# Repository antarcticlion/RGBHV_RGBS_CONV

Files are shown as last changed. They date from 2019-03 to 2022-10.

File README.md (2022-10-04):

# RGB MULTI CONV

Display/Monitor video signal converter PCB for Japanese Retro PC (RGBHV &lt;--> RGBS ./ etc. )

##概要

主に日本製のレトロPCのRGB信号を、コネクタ変換・信号変換・分岐を行うボードです。
Rev1.5でサブボードをスタックして扱うコネクタを増やせるようにしています。
プロジェクトにはKiCad PCB 5.0用のプロジェクトファイルとガーバーが含まれます。

##外観
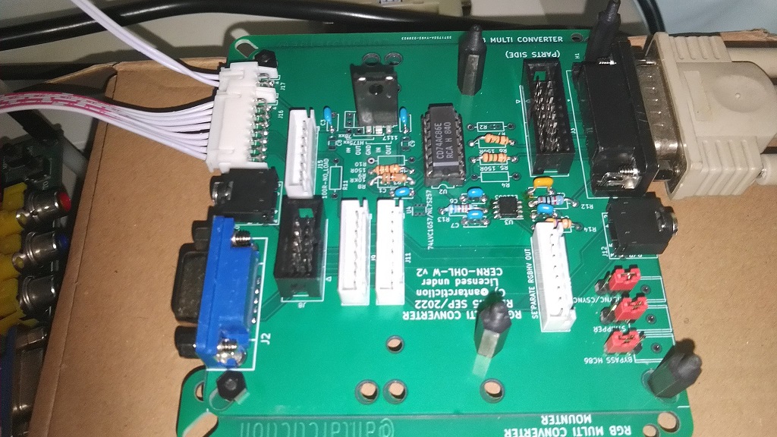
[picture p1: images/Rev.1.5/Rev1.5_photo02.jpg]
Rev15 converter pcb_photo 1
  
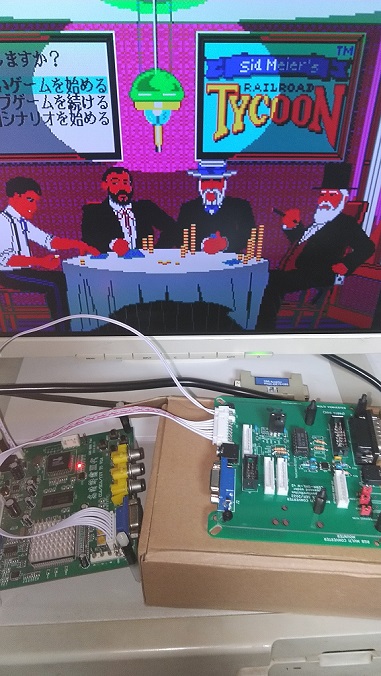
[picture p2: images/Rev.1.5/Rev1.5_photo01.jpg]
Rev15 converter pcb_photo 1
  

## 動作確認済機種
### Video signal src.
- IBM-PC compatible (VGA)  
- PC-8801mk2 (Digital RGB 8p)  
- PC-8801mk2MR/FH (Digital RGB 8p/Analog RGB DA15)  
- PC-9801DA/U2 (Analog RGB DA15)  
- PC-9801VX41 (Digital RGB 8p/Analog RGB DA15)  
- X1 Turbo model40 (Digital RGB 8p)  
- X1 Turbo model30 (Digital RGB 6p)  
- MZ-700 (Digital RGB 8p)  
- FM-7 (Digital RGB 8p)  
- FM-new7 (Digital RGB 8p)  
- BASIC Master Level 3 (Digital RGB 8p)  
- Arcade-Game PCBs (クイズココロジー2／上海2／子育てクイズ マイエンジェル）(信号分岐、コネクタ変換)
- 上記の他、PC8001シリーズ(Digital RGB)で動作報告をいただいております。ありがとうございます。
### Video signal dst.
- GBS-8200/GBS-8220/HD9800V/HD-VC9900(RGBS)
- Some VGA monitors (DE15/VGA)

***
[概要](https://github.com/antarcticlion/RGBHV_RGBS_CONV/wiki)  
[作り方](https://github.com/antarcticlion/RGBHV_RGBS_CONV/wiki/How-to-make)  
[デザインと説明](https://github.com/antarcticlion/RGBHV_RGBS_CONV/wiki/Design)  
[その他](https://github.com/antarcticlion/RGBHV_RGBS_CONV/wiki/Miscellaneous)  
[リリースノート](https://github.com/antarcticlion/RGBHV_RGBS_CONV/wiki/Release-note)  

***
最新版 Rev1.5A
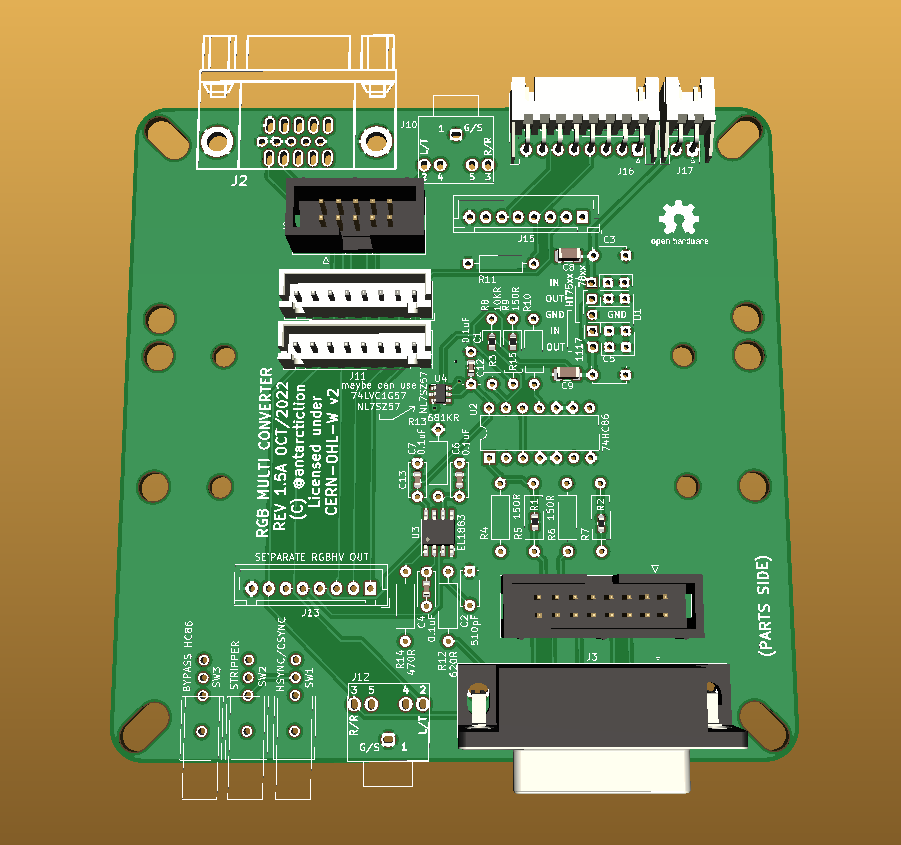
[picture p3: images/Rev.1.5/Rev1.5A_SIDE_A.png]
Rev15A converter pcb_art 1
  
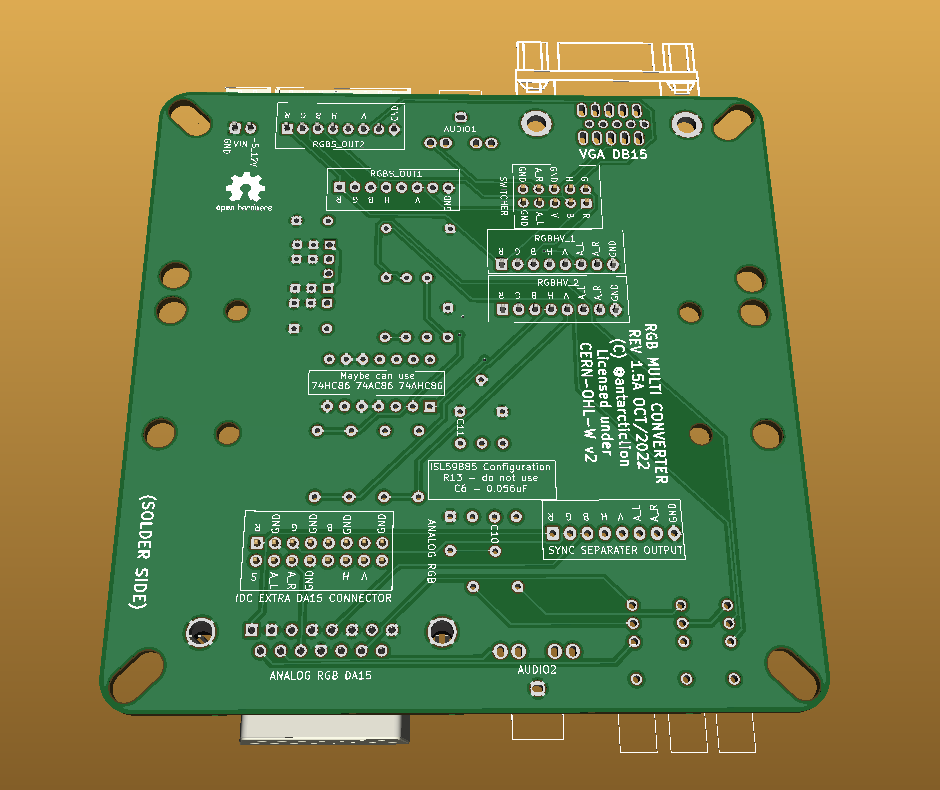
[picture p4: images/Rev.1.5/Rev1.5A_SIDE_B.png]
Rev15A converter pcb_art 2
  

***
# Lastest Gerber

### 1.5A  
https://github.com/antarcticlion/RGBHV_RGBS_CONV/blob/master/RGBHV_RGBS_CONV_15A.zip メインボード
https://github.com/antarcticlion/RGBHV_RGBS_CONV/blob/master/RGBHV_RGBS_CONV_EXTRA1_15.zip　デジタルRGBサブボード
https://github.com/antarcticlion/RGBHV_RGBS_CONV/blob/master/RGBHV_RGBS_CONV_stack_15.zip　GBSスタック用サブボード

## Arcive

### 1.0D  
https://github.com/antarcticlion/RGBHV_RGBS_CONV/blob/master/RGBHV_RGBS_CONV_10D.zip

***
# Changes Log  
| Revision | Date | Description |
|:---|:---|:---|
|1.5A release |2022/10/03 | スイッチのスルーホールサイズを変更 |
|1.5 release candidate |2022/09/23 | DE15/DA15を残し他のコネクタは小基板化、EL1883用パターンを追加、各種切り替えスイッチを付ける |
||2022/09/23 | 最新のガーバーファイルを残して古いものは削除 |
|1.0D release |2021/07/29 | DIN8コネクタのフットプリントが裏表逆になっていたのをFIX |
|1.0C release |2021/07/09 | RGBSへの音声パターンカット、レギュレータの足配置バリエーションの追加 |
|1.0B release |2021/05/11 | 3.3Vレギュレータによる電源安定化、3.3V駆動の5VトレラントCMOSロジックでGBS出力の無調整化(SN74AHC86N推奨) |
|0.5B release |2020/06/10 | RGBS出力に多回転VRを追加し、出力レベルを下げられるコネクタを用意。(GBS8200/8220のCSYNC信号不安定対策) |
|0.5A release |2019/08/28 | あまり使わないコネクタと、動悸分離回路を削除、RGBHV DA15のエッジ端コネクタを追加 |
|0.4A release candidate |2019/03/04 | コネクタ位置調整、DCジャック追加 |
|0.4 |2019/03/04 | first release. (experimental) |
|0.1～0.3 | N/A | private |

***
# ライセンス

2022/06/04 
Rev1.0D以降のライセンスを CERN Open Hardware Licence Version 2 - Weakly Reciprocal に変更します。
以前のバージョンのアーカイブは近日消します。

https://spdx.org/licenses/CERN-OHL-W-2.0.html
PDF https://github.com/antarcticlion/RGBHV_RGBS_CONV/blob/master/cern_ohl_w_v2.pdf
HOWTO https://github.com/antarcticlion/RGBHV_RGBS_CONV/blob/master/cern_ohl_w_v2_howto.pdf

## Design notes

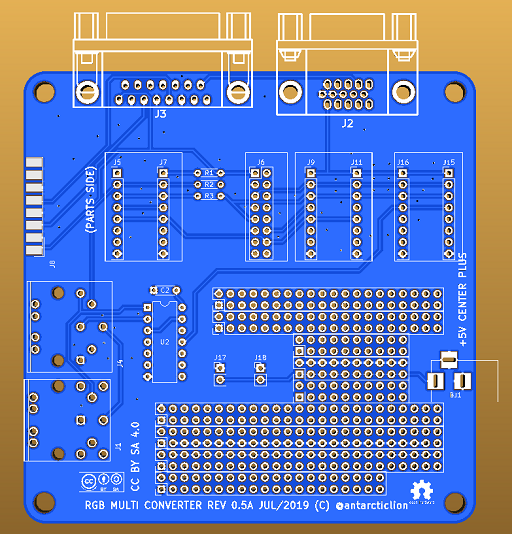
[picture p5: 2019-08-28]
pcb_art_rev5a_omote.jpg

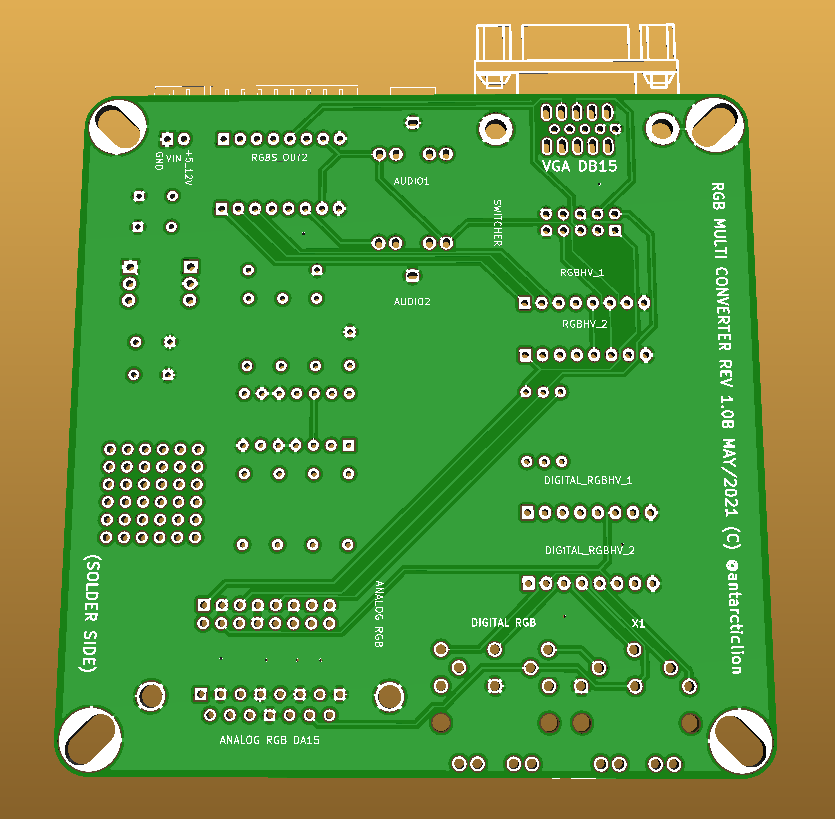
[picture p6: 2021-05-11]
10B_SIDEB.png

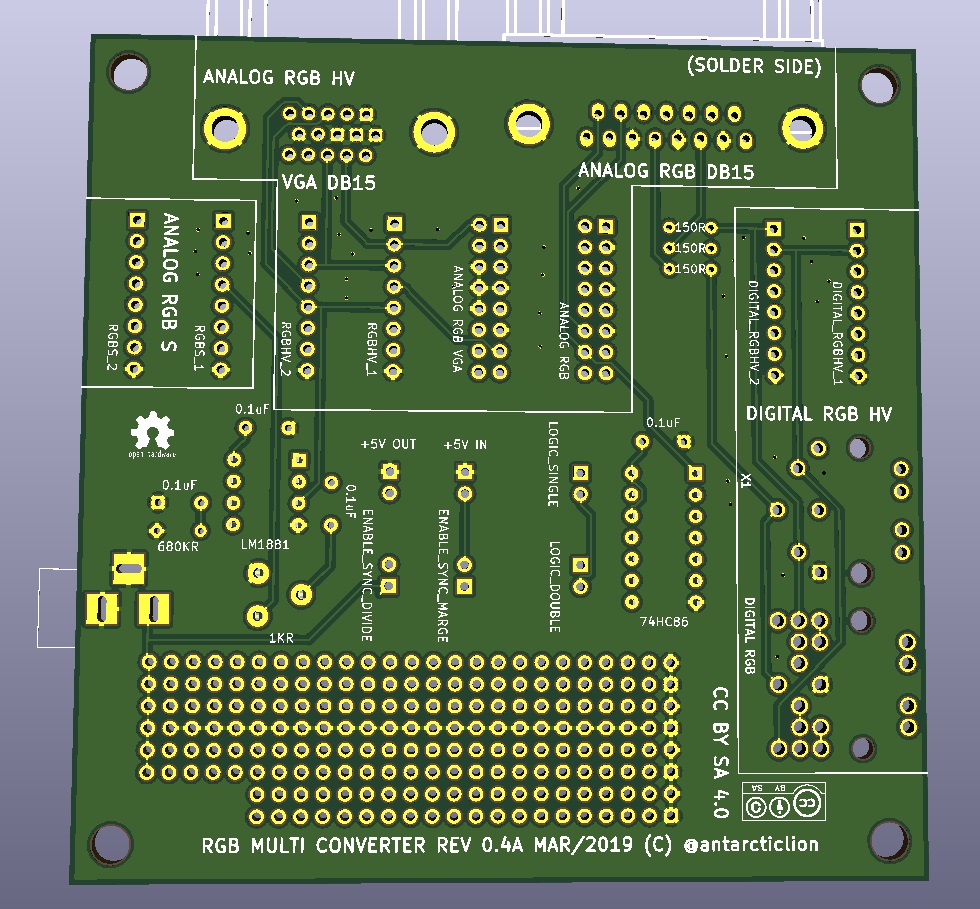
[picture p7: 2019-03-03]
pcb_art_rev5ura.jpg

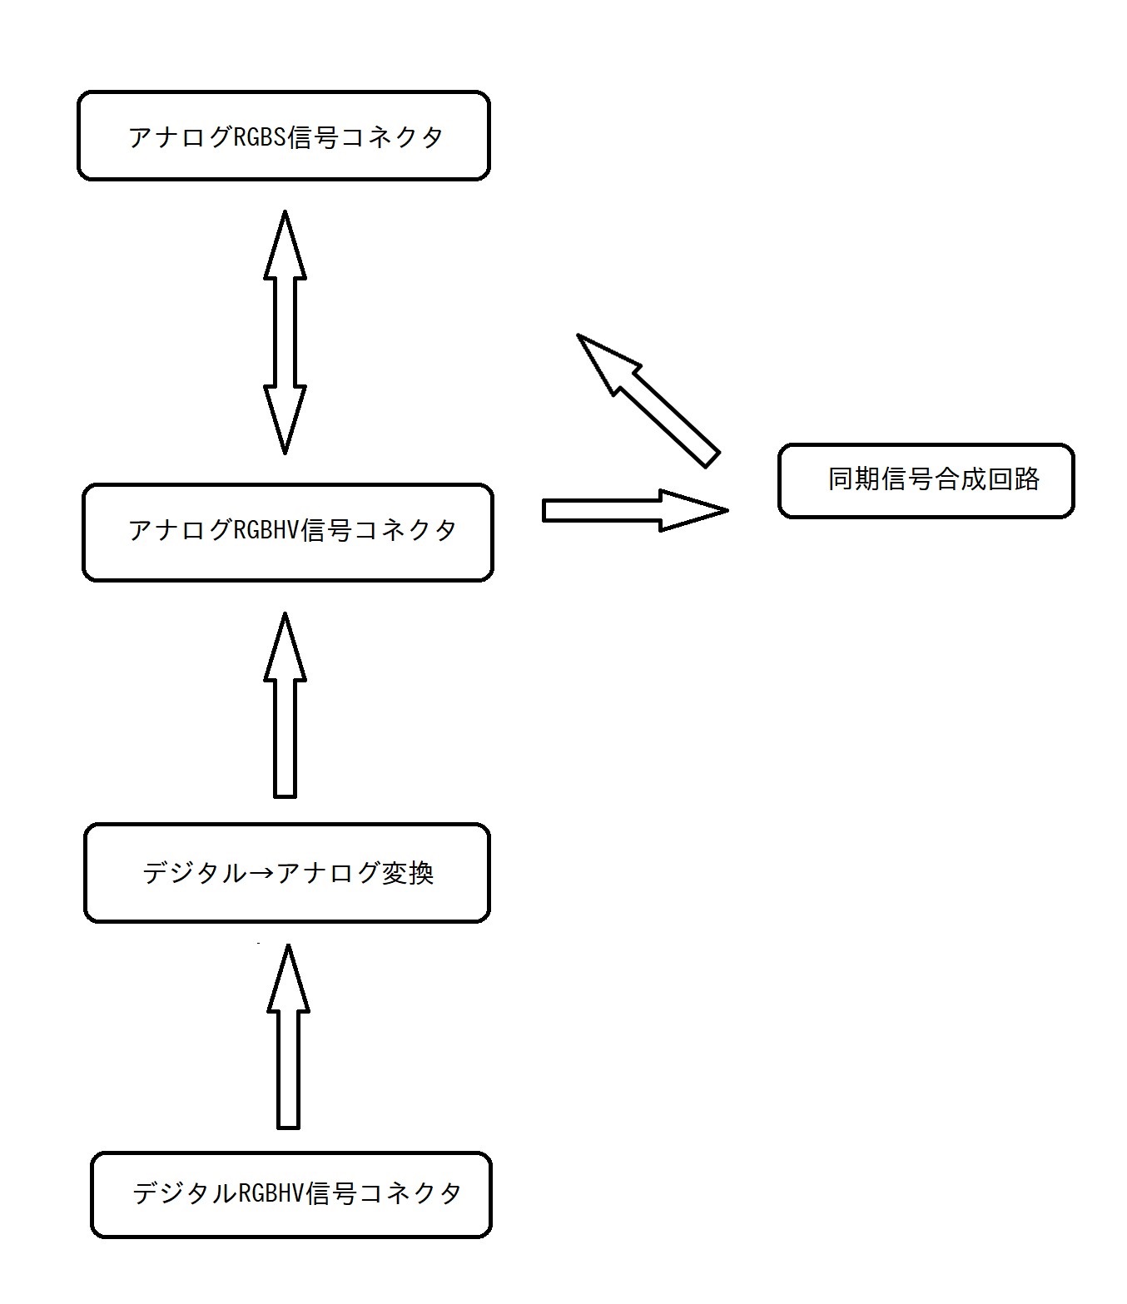
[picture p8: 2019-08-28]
part_dsc.jpg

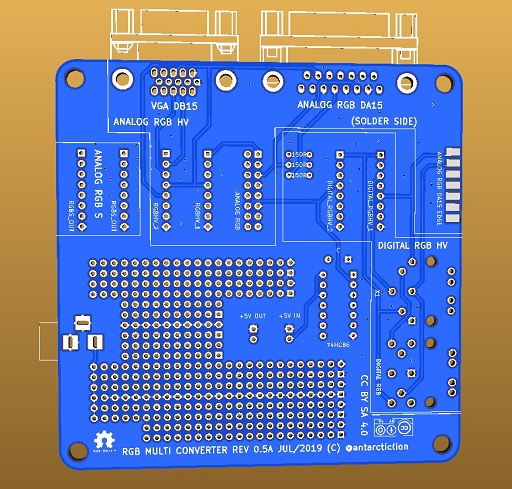
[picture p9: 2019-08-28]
pcb_art_rev5a_ura.jpg

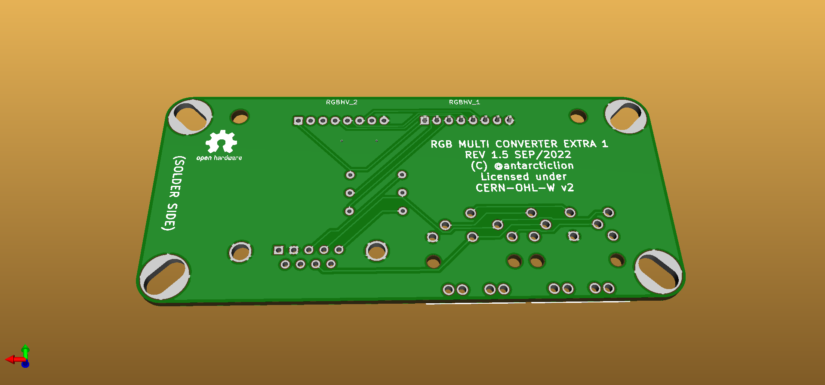
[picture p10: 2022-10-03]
images/Rev.1.5/Rev1.5_EXTRA1_SIDE_B.png

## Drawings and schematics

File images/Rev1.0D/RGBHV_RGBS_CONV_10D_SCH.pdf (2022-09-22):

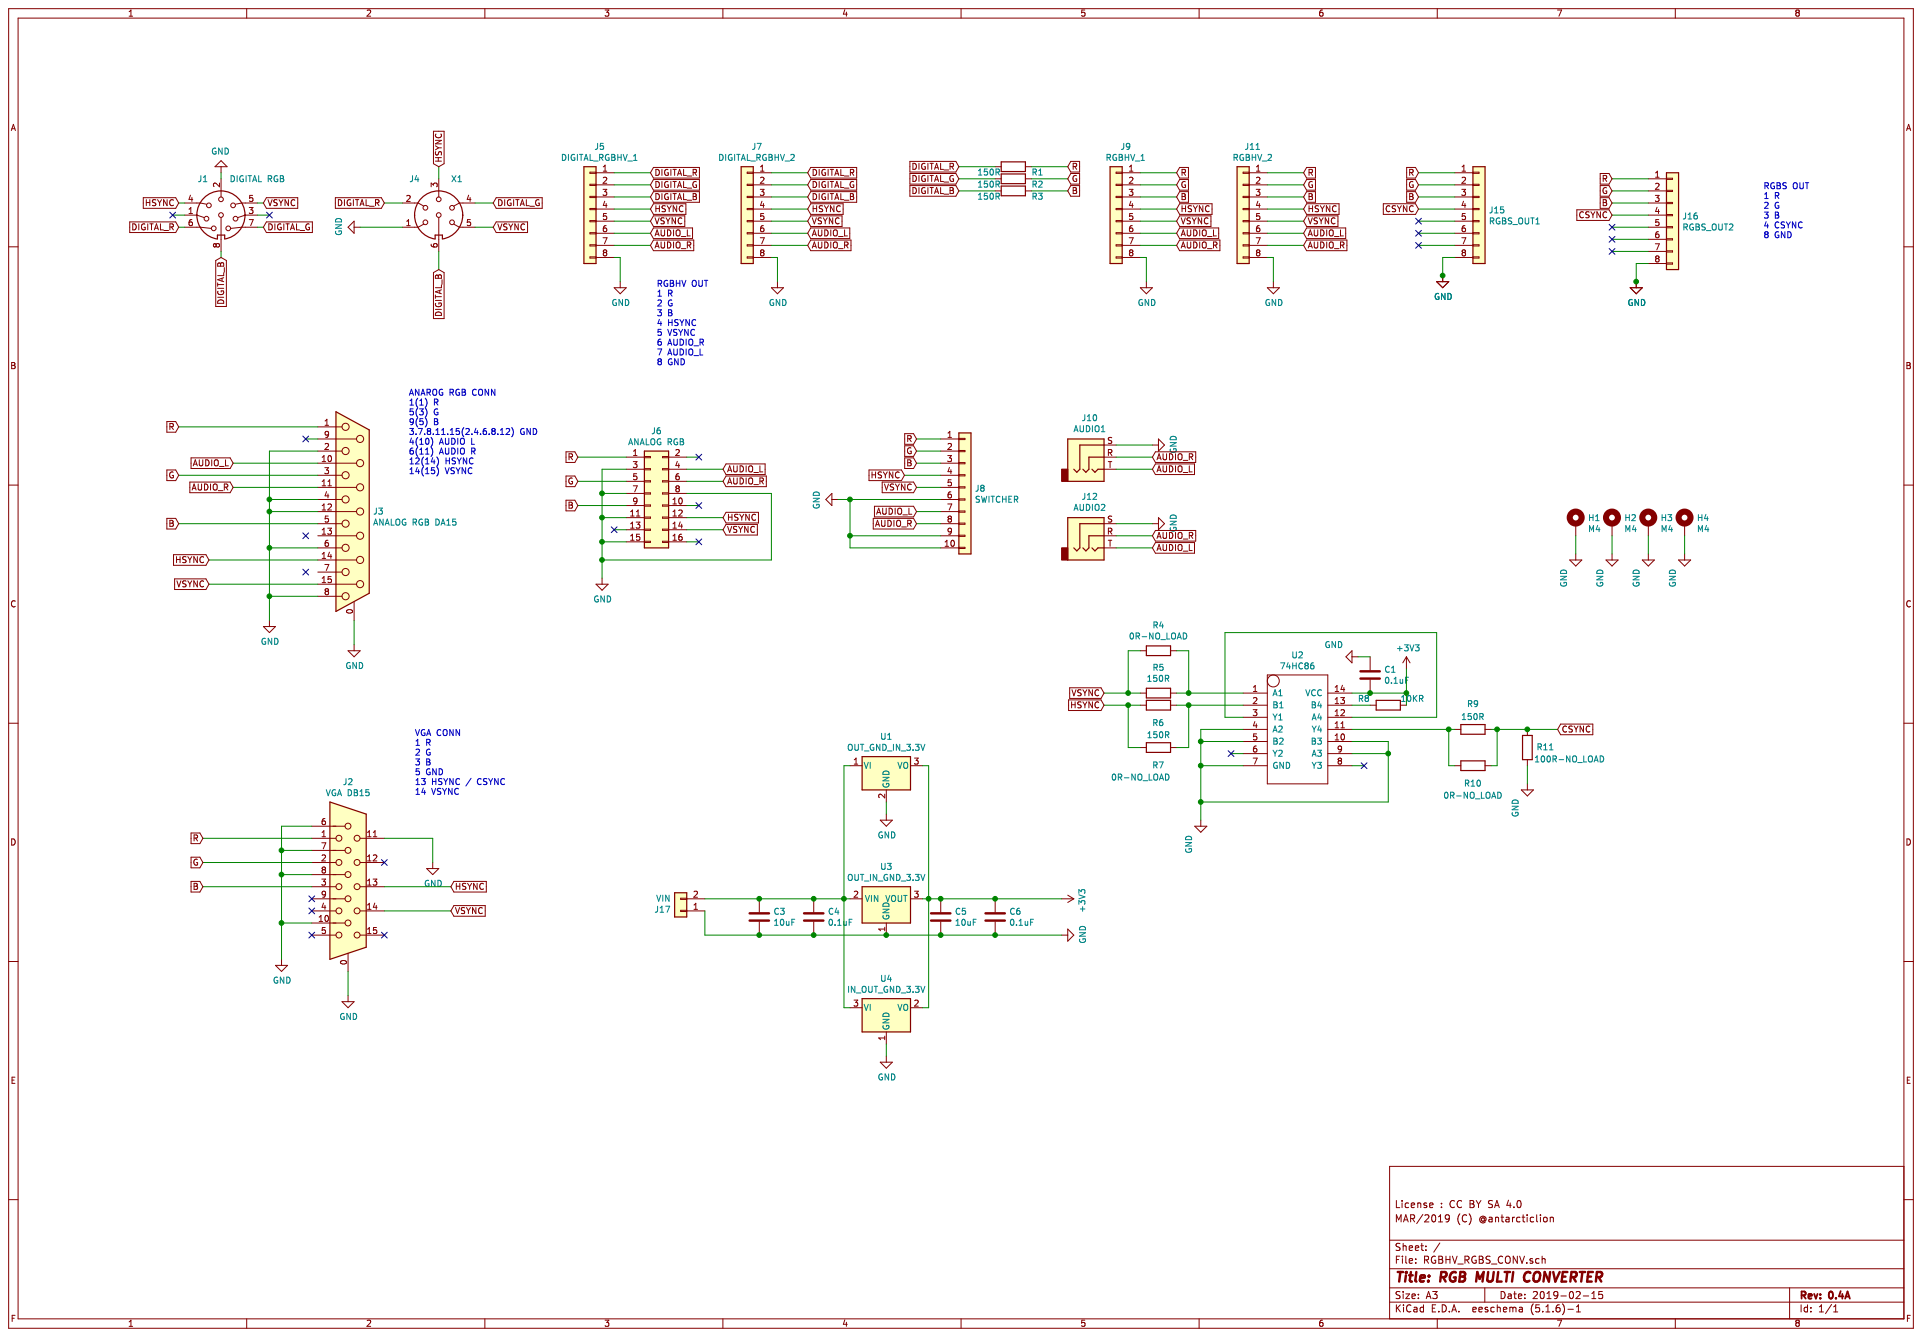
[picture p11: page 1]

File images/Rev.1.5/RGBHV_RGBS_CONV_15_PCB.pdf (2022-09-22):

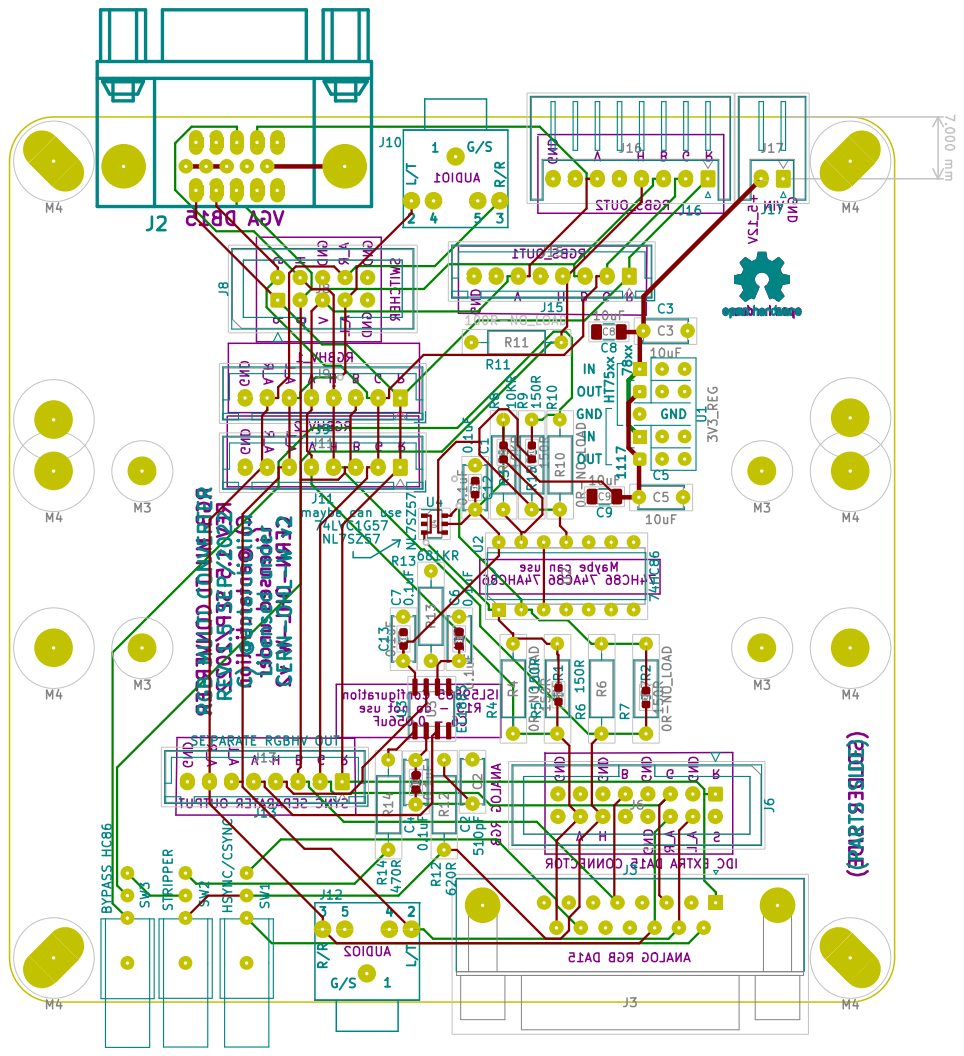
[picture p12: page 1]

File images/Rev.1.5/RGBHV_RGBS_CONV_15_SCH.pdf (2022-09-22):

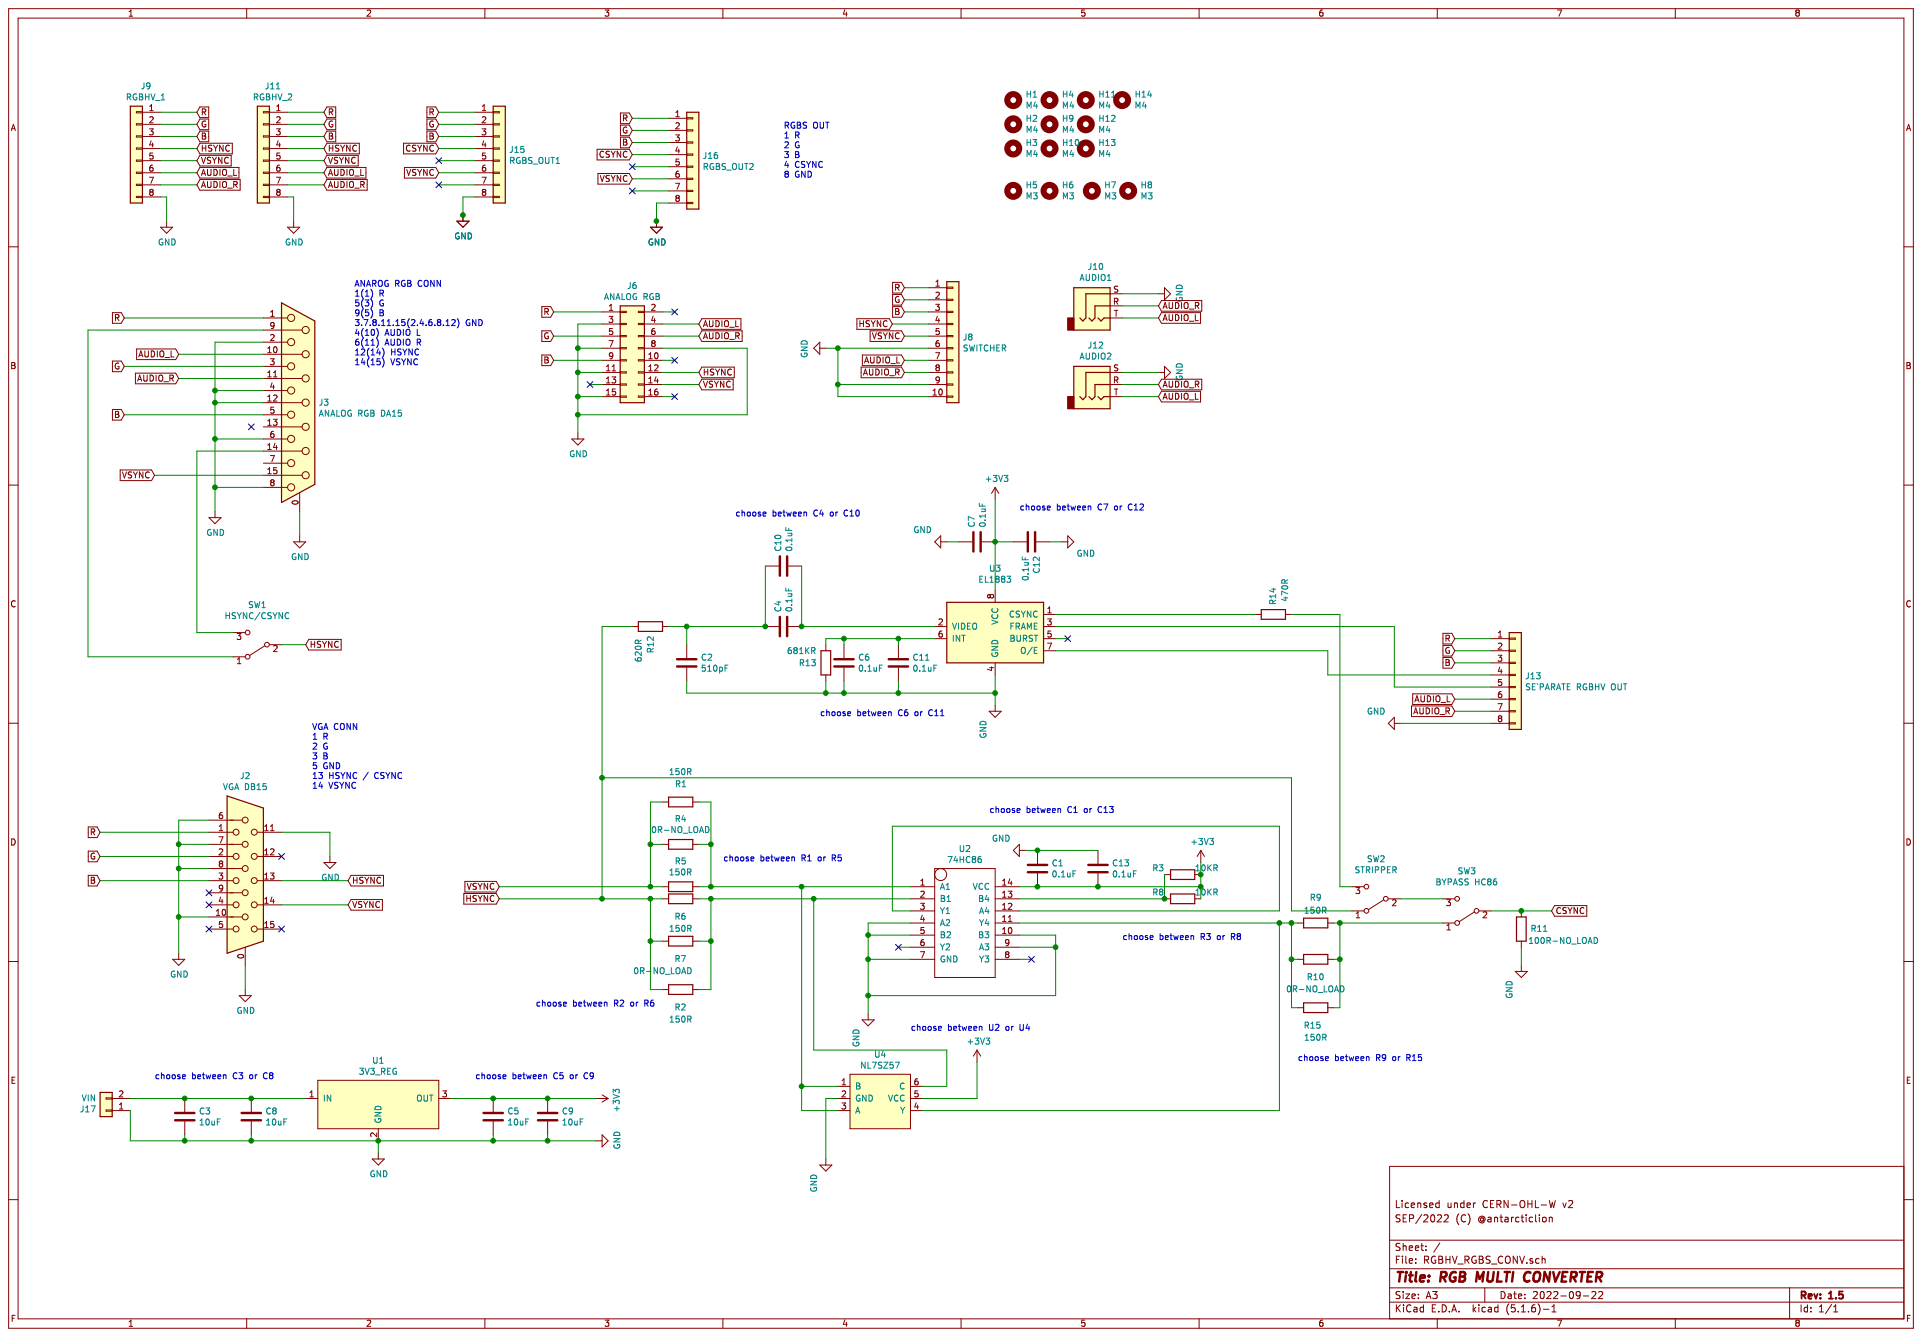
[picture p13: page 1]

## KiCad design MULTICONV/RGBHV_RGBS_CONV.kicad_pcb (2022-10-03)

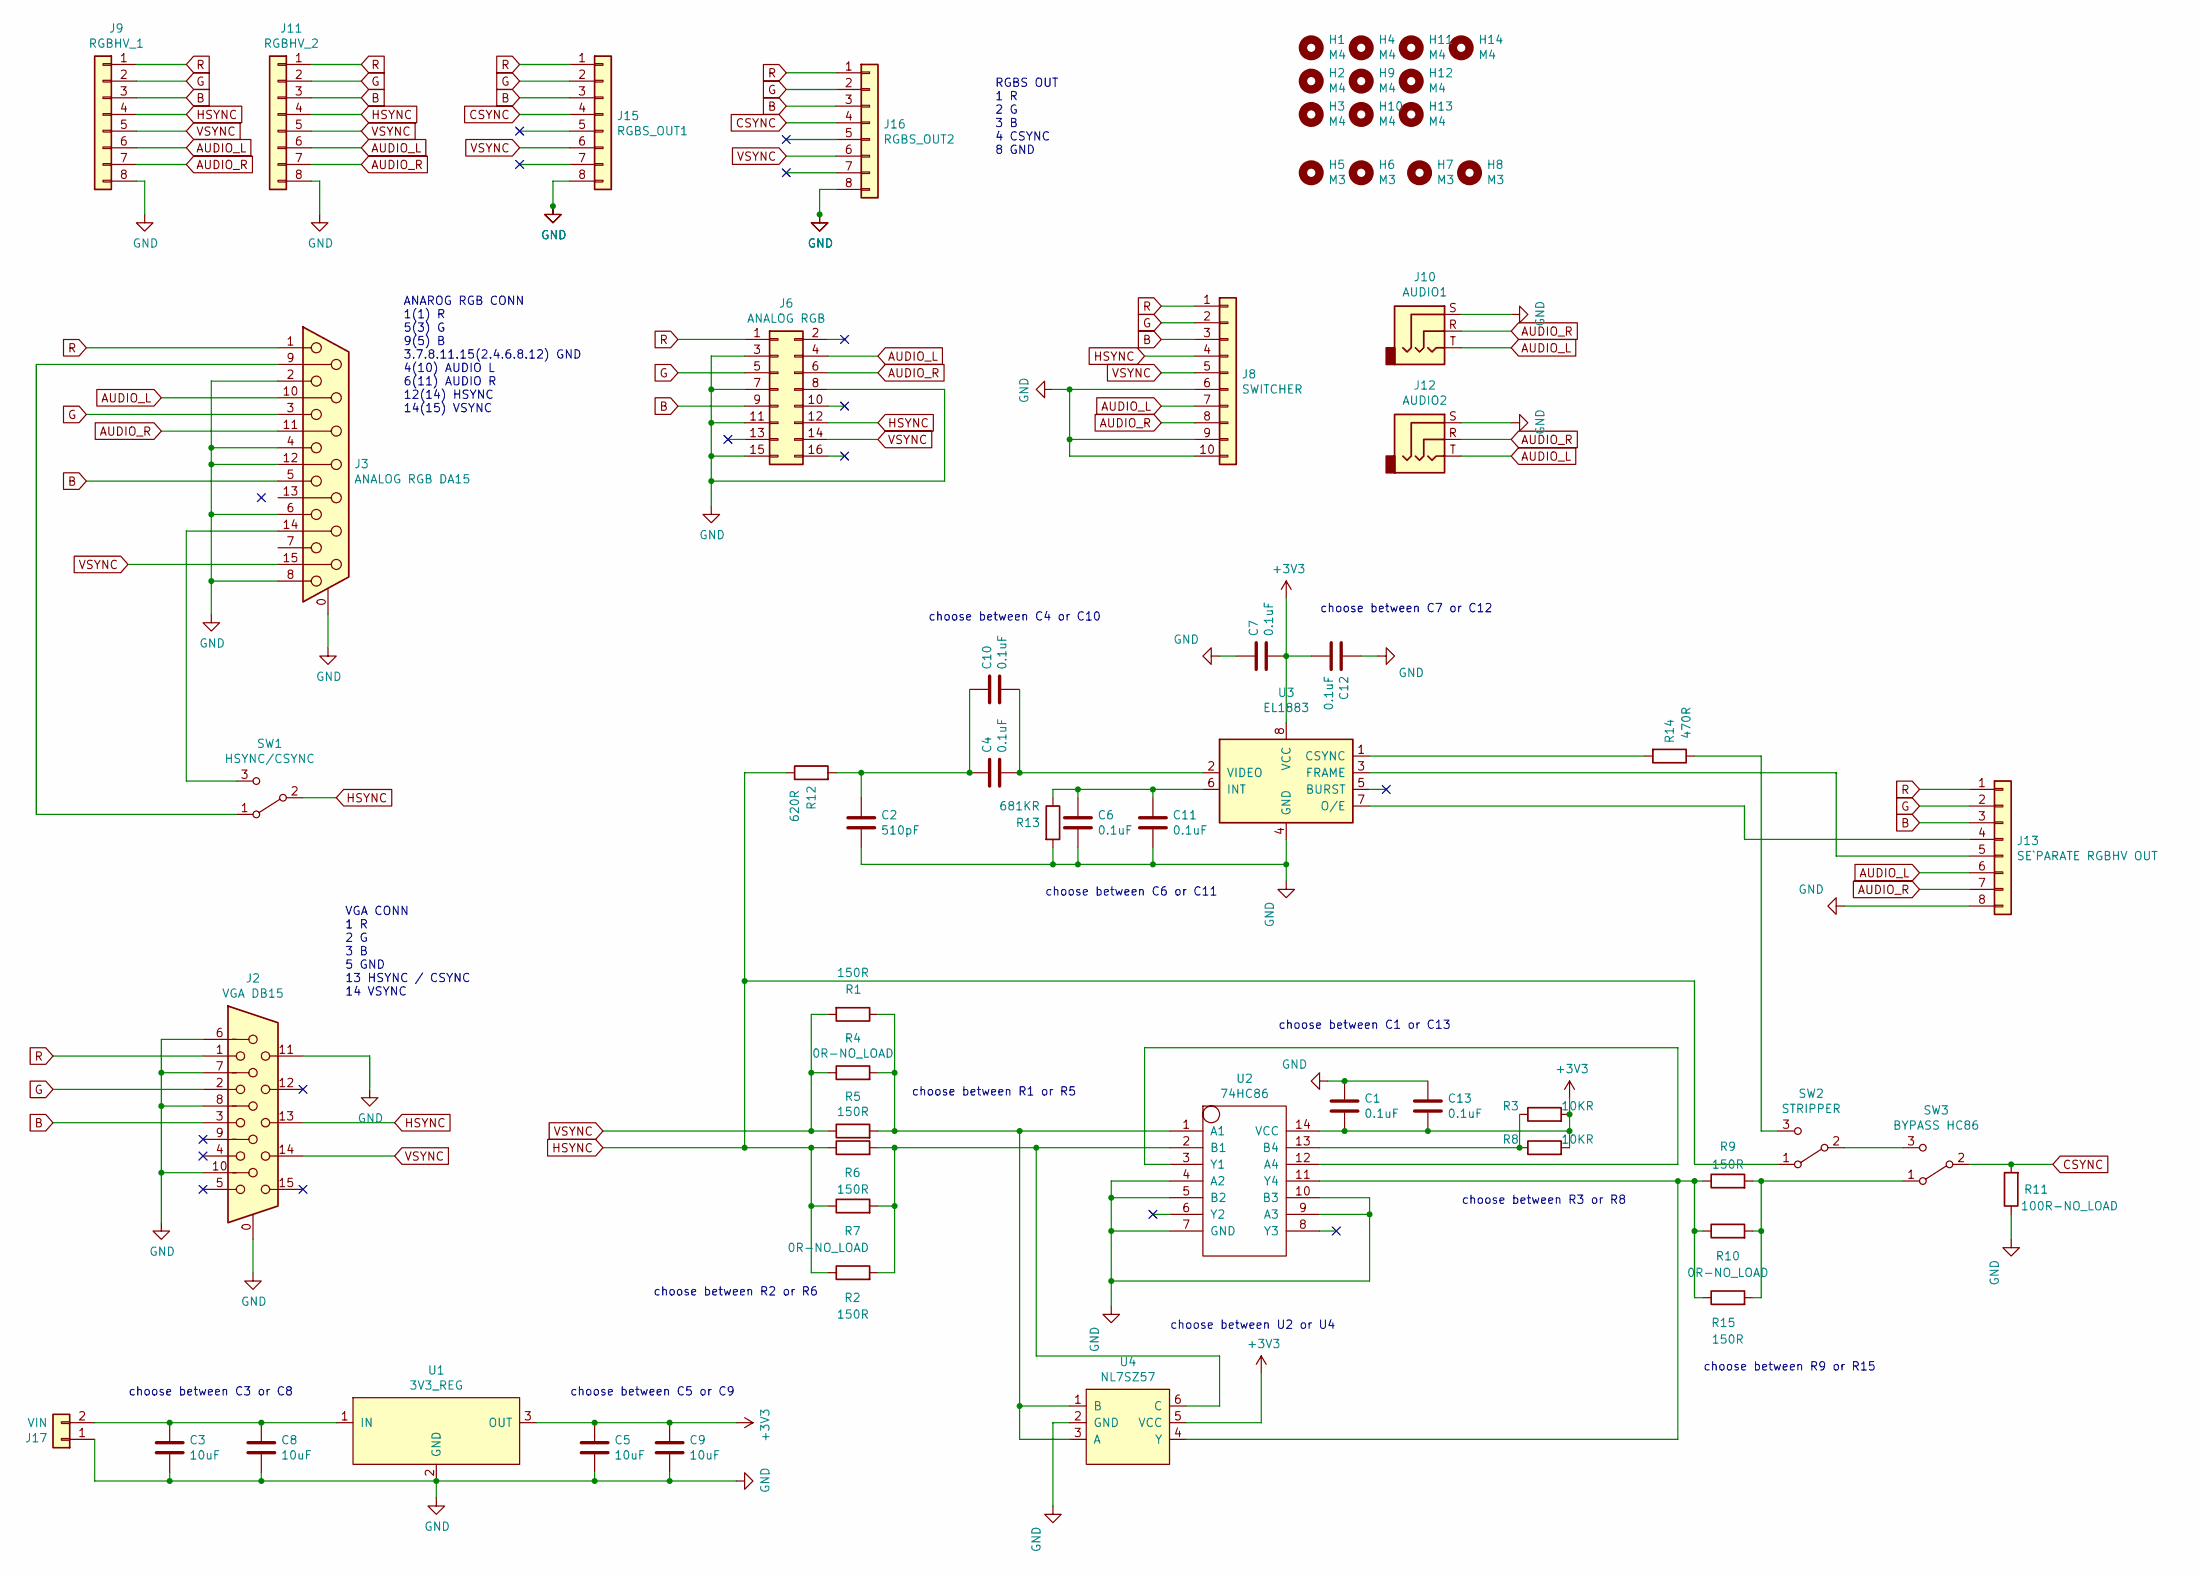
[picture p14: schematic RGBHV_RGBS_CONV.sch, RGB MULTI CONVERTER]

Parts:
C1, C4, C6, C7: 0.1uF; C_Disc_D5.0mm_W2.5mm_P5.00mm
C2: 510pF; C_Disc_D5.0mm_W2.5mm_P5.00mm
C3, C5: 10uF; C_Disc_D5.0mm_W2.5mm_P5.00mm
C8, C9: 10uF; C_1206_3216Metric
C10, C11, C12, C13: 0.1uF; C_0603_1608Metric
H1, H2, H3, H4, H9, H10, H11, H12, H13, H14: M4; MountingHole_4.3mm_M4
H5, H6, H7, H8: M3; MountingHole_3.2mm_M3
J2: VGA DB15; DB_15F-VGA_L
J3: ANALOG RGB DA15; DSUB-15_Female_Horizontal_P2.77x2.84mm_EdgePinOffset4.94mm_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
J6: ANALOG RGB; IDC-Header_2x08_P2.54mm_Vertical
J8: SWITCHER; IDC-Header_2x05_P2.54mm_Vertical
J9: RGBHV_1; JST_XH_B8B-XH-A_1x08_P2.50mm_Vertical
J10: AUDIO1; PJ-3900-04
J11: RGBHV_2; JST_XH_B8B-XH-A_1x08_P2.50mm_Vertical
J12: AUDIO2; PJ-3900-04
J13: SE`PARATE RGBHV OUT; JST_XH_B8B-XH-A_1x08_P2.50mm_Vertical
J15: RGBS_OUT1; JST_XH_B8B-XH-A_1x08_P2.50mm_Vertical
J16: RGBS_OUT2; JST_XH_S8B-XH-A_1x08_P2.50mm_Horizontal
J17: VIN; JST_XH_S2B-XH-A_1x02_P2.50mm_Horizontal
R1, R2, R15: 150R; R_0603_1608Metric
R3: 10KR; R_0603_1608Metric
R4, R7, R10: 0R-NO_LOAD; R_Axial_DIN0207_L6.3mm_D2.5mm_P10.16mm_Horizontal
R5, R6, R9: 150R; R_Axial_DIN0207_L6.3mm_D2.5mm_P10.16mm_Horizontal
R8: 10KR; R_Axial_DIN0207_L6.3mm_D2.5mm_P10.16mm_Horizontal
R11: 100R-NO_LOAD; R_Axial_DIN0207_L6.3mm_D2.5mm_P10.16mm_Horizontal
R12: 620R; R_Axial_DIN0207_L6.3mm_D2.5mm_P10.16mm_Horizontal
R13: 681KR; R_Axial_DIN0207_L6.3mm_D2.5mm_P10.16mm_Horizontal
R14: 470R; R_Axial_DIN0207_L6.3mm_D2.5mm_P10.16mm_Horizontal
SW1: HSYNC/CSYNC; 2MS1T1B4M7QES
SW2: STRIPPER; 2MS1T1B4M7QES
SW3: BYPASS HC86; 2MS1T1B4M7QES
U1: 3V3_REG; PIN_Unified_LDO
U2: 74HC86; DIP-14_W7.62mm
U3: EL1883; SOIC-8_3.9x4.9mm_P1.27mm
U4: NL7SZ57; TSOP-6_1.65x3.05mm_P0.95mm

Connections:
+3V3: C1.2, C5.1, C7.2, C9.1, C12.2, C13.2, R3.2, R8.2, U1.3 (OUT), U2.14 (VCC), U3.8 (VCC), U4.5 (VCC)
AUDIO_L: J3.10, J6.4, J8.7, J9.6, J10.T, J11.6, J12.T, J13.6
AUDIO_R: J3.11 (P111), J6.6, J8.8, J9.7, J10.R, J11.7, J12.R, J13.7
B: J2.3, J3.5, J6.9, J8.3, J9.3, J11.3, J13.3, J15.3, J16.3
CSYNC: J15.4, J16.4, R11.2, SW3.2 (B)
G: J2.2, J3.3, J6.5, J8.2, J9.2, J11.2, J13.2, J15.2, J16.2
GND: C1.1, C2.2, C3.2, C5.2, C6.2, C7.1, C8.2, C9.2, C11.2, C12.1, C13.1, J2.0, J2.6, J2.7, J2.8, J2.10, J2.11, J3.0 (PAD), J3.2, J3.4, J3.6, J3.8, J3.12, J6.3, J6.7, J6.8, J6.11, J6.15, J8.6, J8.9, J8.10, J9.8, J10.S, J11.8, J12.S, J13.8, J15.8, J16.8, J17.1, R11.1, R13.2, U1.2 (GND), U2.4 (A2), U2.5 (B2), U2.7 (GND), U2.9 (A3), U2.10 (B3), U3.4 (GND), U4.2 (GND)
HSYNC: J2.13, J6.12, J8.4, J9.4, J11.4, R2.1, R6.1, R7.1, R12.1, SW1.2 (B), SW2.1 (A)
unnamed: C3.1, C8.1, J17.2, U1.1 (IN)
unnamed: C2.1, C4.1, C10.1, R12.2
unnamed: C4.2, C10.2, U3.2 (VIDEO)
unnamed: C6.1, C11.1, R13.1, U3.6 (INT)
unnamed: J3.9, SW1.1 (A)
unnamed: J3.14, SW1.3 (C)
unnamed: J13.4, U3.7 (O/E)
unnamed: J13.5, U3.3 (FRAME)
unnamed: R1.1, R4.2, R5.2, U2.1 (A1), U4.1 (B), U4.3 (A)
unnamed: R2.2, R6.2, R7.2, U2.2 (B1), U4.6 (C)
unnamed: R3.1, R8.1, U2.13 (B4)
unnamed: R9.1, R10.1, R15.1, U2.11 (Y4), U4.4 (Y)
unnamed: R9.2, R10.2, R15.2, SW3.1 (A)
unnamed: R14.1, SW2.3 (C)
unnamed: R14.2, U3.1 (CSYNC)
unnamed: SW2.2 (B), SW3.3 (C)
unnamed: U2.3 (Y1), U2.12 (A4)
R: J2.1, J3.1, J6.1, J8.1, J9.1, J11.1, J13.1, J15.1, J16.1
VSYNC: J2.14, J3.15, J6.14, J8.5, J9.5, J11.5, J15.6, J16.6, R1.2, R4.1, R5.1

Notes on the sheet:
ANAROG RGB CONN 1(1) R 5(3) G 9(5) B 3.7.8.11.15(2.4.6.8.12) GND 4(10) AUDIO L 6(11) AUDIO R 12(14) HSYNC 14(15) VSYNC
RGBS OUT 1 R 2 G 3 B 4 CSYNC 8 GND
VGA CONN 1 R 2 G 3 B 5 GND 13 HSYNC / CSYNC 14 VSYNC
choose between R1 or R5
choose between R2 or R6
choose between U2 or U4
choose between C1 or C13
choose between R3 or R8
choose between R9 or R15
choose between C7 or C12
choose between C4 or C10
choose between C6 or C11
choose between C5 or C9
choose between C3 or C8

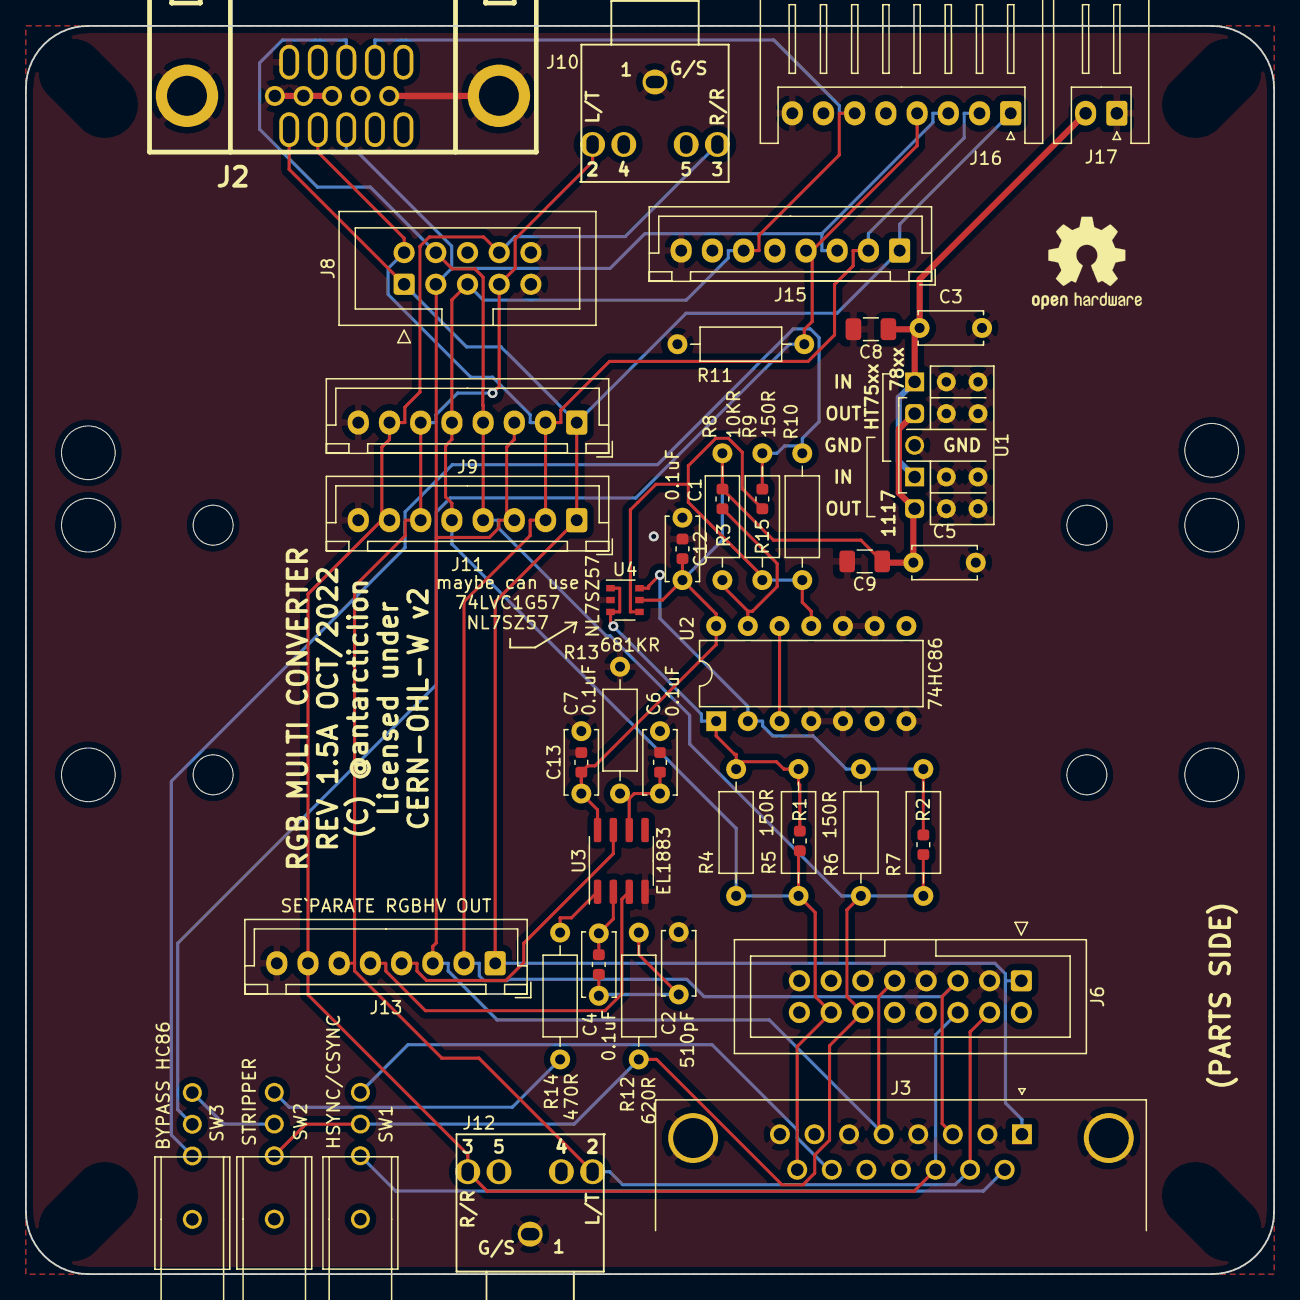
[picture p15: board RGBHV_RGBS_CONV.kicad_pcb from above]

Board: 2 copper layers, 100.0 x 100.0 mm, 61 parts (0 on the bottom side), 27 nets.

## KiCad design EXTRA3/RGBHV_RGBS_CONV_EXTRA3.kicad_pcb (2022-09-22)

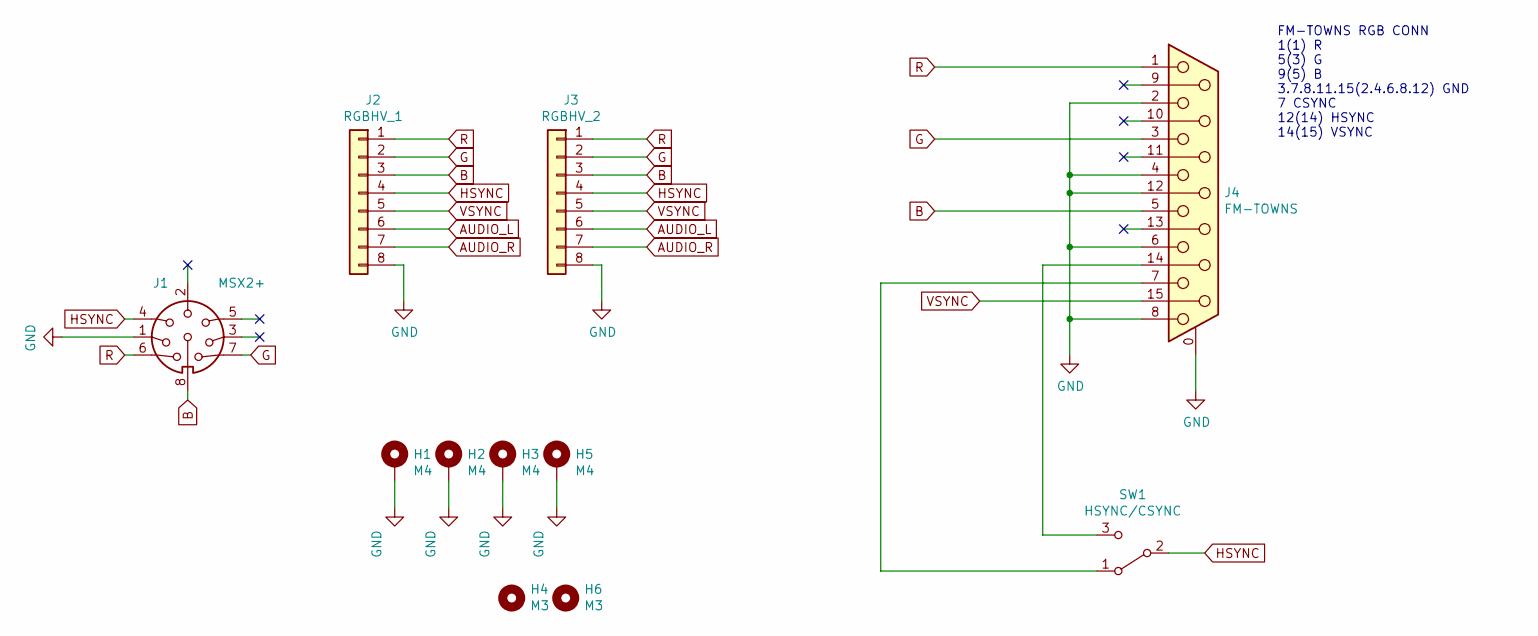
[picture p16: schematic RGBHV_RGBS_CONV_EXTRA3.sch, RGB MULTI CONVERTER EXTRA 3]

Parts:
H1, H2, H3, H5: M4; MountingHole_4.3mm_M4_Pad
H4, H6: M3; MountingHole_3.2mm_M3
J1: MSX2+; DIN 8 PCB
J2: RGBHV_1; JST_XH_B8B-XH-A_1x08_P2.50mm_Vertical
J3: RGBHV_2; JST_XH_B8B-XH-A_1x08_P2.50mm_Vertical
J4: FM-TOWNS; DSUB-15_Female_Horizontal_P2.77x2.84mm_EdgePinOffset4.94mm_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
SW1: HSYNC/CSYNC; 2MS1T1B4M7QES

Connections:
AUDIO_L: J2.6, J3.6
AUDIO_R: J2.7, J3.7
B: J1.8, J2.3, J3.3, J4.5
G: J1.7, J2.2, J3.2, J4.3
GND: H1.1, H2.1, H3.1, H5.1, J1.1, J2.8, J3.8, J4.0 (PAD), J4.2, J4.4, J4.6, J4.8, J4.12
HSYNC: J1.4, J2.4, J3.4, SW1.2 (B)
unnamed: J4.7, SW1.1 (A)
unnamed: J4.14, SW1.3 (C)
R: J1.6, J2.1, J3.1, J4.1
VSYNC: J2.5, J3.5, J4.15

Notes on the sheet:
FM-TOWNS RGB CONN 1(1) R 5(3) G 9(5) B 3.7.8.11.15(2.4.6.8.12) GND 7 CSYNC 12(14) HSYNC 14(15) VSYNC

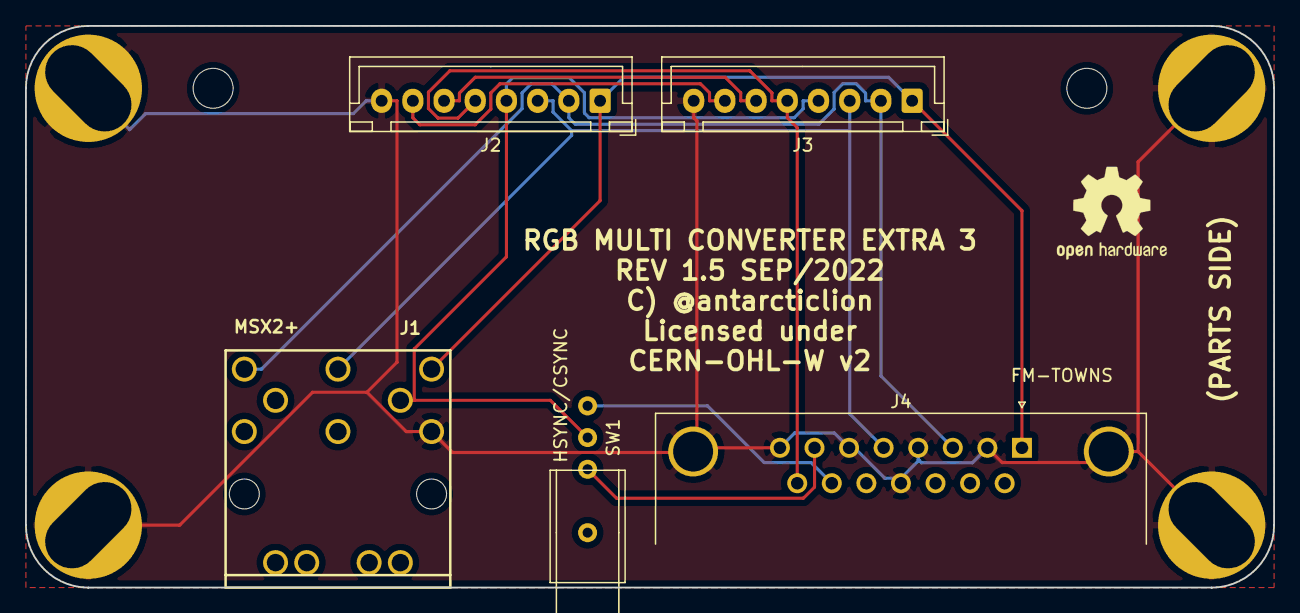
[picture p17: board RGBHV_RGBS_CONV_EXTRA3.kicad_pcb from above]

Board: 2 copper layers, 100.0 x 45.0 mm, 11 parts (0 on the bottom side), 10 nets.

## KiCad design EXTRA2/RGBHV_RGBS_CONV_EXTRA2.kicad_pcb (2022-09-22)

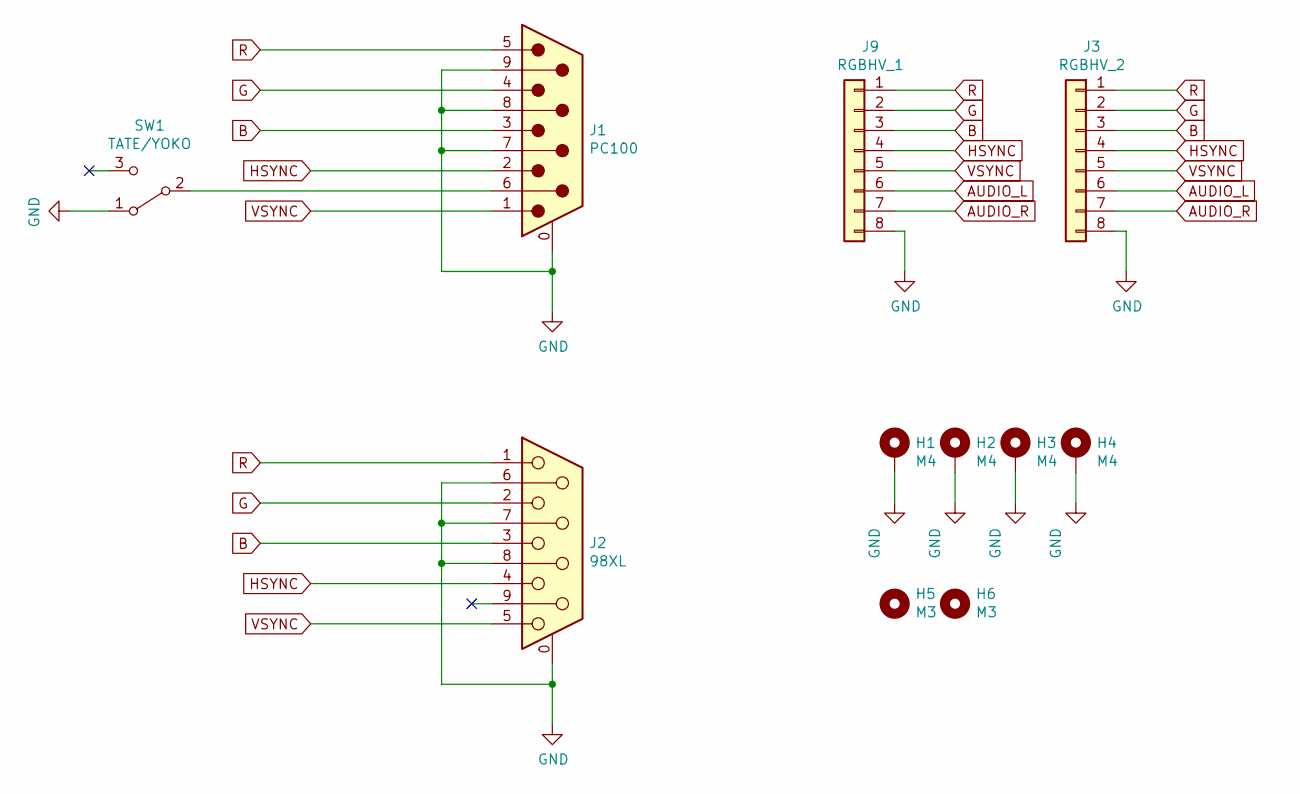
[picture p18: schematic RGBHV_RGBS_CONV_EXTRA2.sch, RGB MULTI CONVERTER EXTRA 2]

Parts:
H1, H2, H3, H4: M4; MountingHole_4.3mm_M4_Pad
H5, H6: M3; MountingHole_3.2mm_M3
J1: PC100; DSUB-9_Male_Horizontal_P2.77x2.84mm_EdgePinOffset4.94mm_Hou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
J2: 98XL; DSUB-9_Female_Horizontal_P2.77x2.84mm_EdgePinOffset4.94mm_H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
J3: RGBHV_2; JST_XH_B8B-XH-A_1x08_P2.50mm_Vertical
J9: RGBHV_1; JST_XH_B8B-XH-A_1x08_P2.50mm_Vertical
SW1: TATE/YOKO; 2MS1T1B4M7QES

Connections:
AUDIO_L: J3.6, J9.6
AUDIO_R: J3.7, J9.7
B: J1.3, J2.3, J3.3, J9.3
G: J1.4, J2.2, J3.2, J9.2
GND: H1.1, H2.1, H3.1, H4.1, J1.0 (PAD), J1.7, J1.8, J1.9, J2.0 (PAD), J2.6, J2.7, J2.8, J3.8, J9.8, SW1.1 (A)
HSYNC: J1.2, J2.4, J3.4, J9.4
unnamed: J1.6, SW1.2 (B)
R: J1.5, J2.1, J3.1, J9.1
VSYNC: J1.1, J2.5, J3.5, J9.5

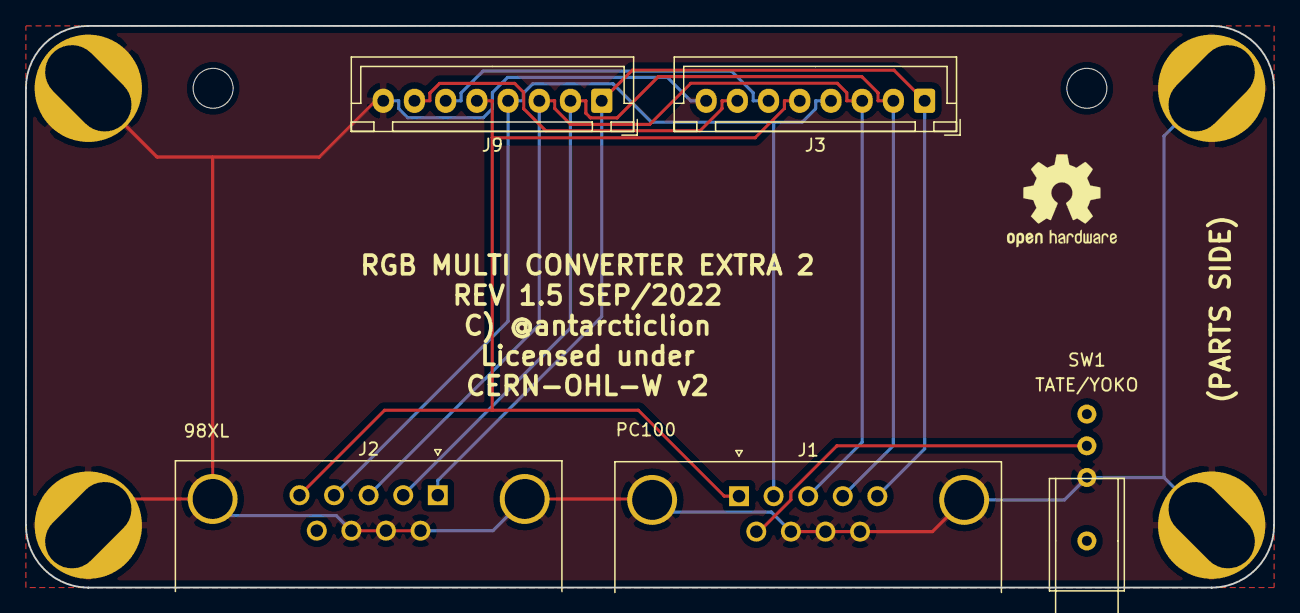
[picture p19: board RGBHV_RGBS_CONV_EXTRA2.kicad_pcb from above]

Board: 2 copper layers, 100.0 x 45.0 mm, 11 parts (0 on the bottom side), 9 nets.

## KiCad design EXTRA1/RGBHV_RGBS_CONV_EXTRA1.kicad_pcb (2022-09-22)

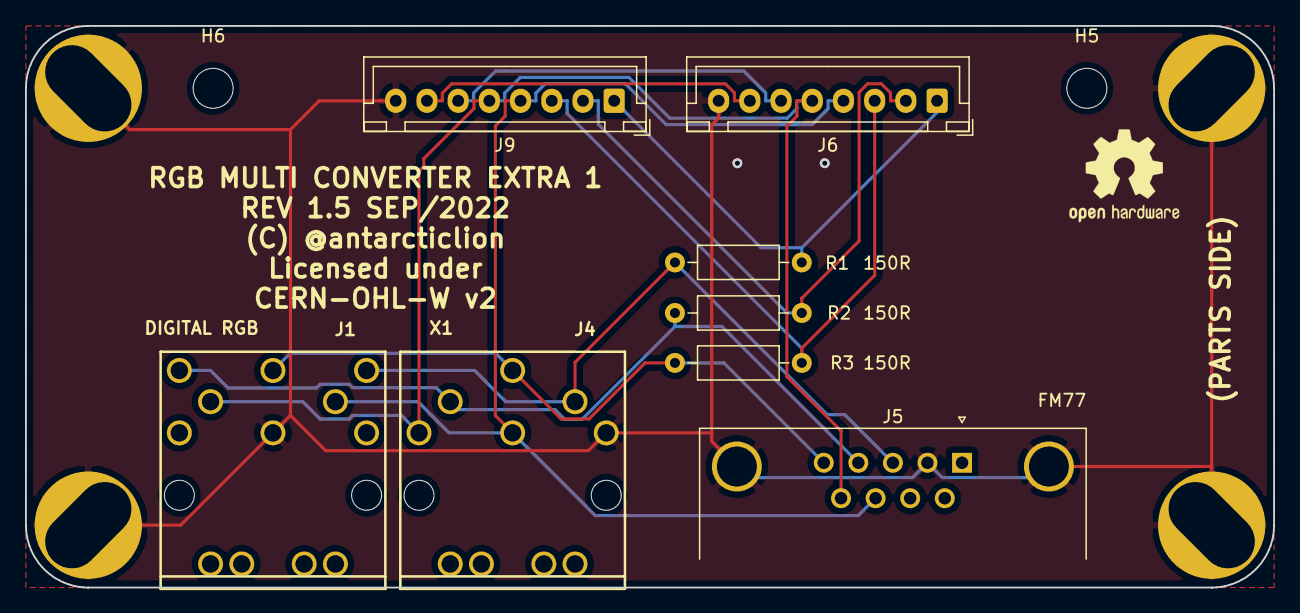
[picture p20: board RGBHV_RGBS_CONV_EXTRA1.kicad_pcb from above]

Board: 2 copper layers, 100.0 x 45.0 mm, 16 parts (1 on the bottom side), 11 nets.

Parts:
H1, H2, H3, H4: M4; MountingHole_4.3mm_M4_Pad
H5, H6: M3; MountingHole_3.2mm_M3
J1: DIGITAL RGB; DIN 8 PCB
J4: X1; DIN_6_PCB
J5: FM77; DSUB-9_Female_Horizontal_P2.77x2.84mm_EdgePinOffset4.94mm_H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
J6: RGBHV_2; JST_XH_B8B-XH-A_1x08_P2.50mm_Vertical
J9: RGBHV_1; JST_XH_B8B-XH-A_1x08_P2.50mm_Vertical
LOGO1, LOGO1#2: OSHW-Logo2_9.8x8mm_SilkScreen
R1, R2, R3: 150R; R_Axial_DIN0207_L6.3mm_D2.5mm_P10.16mm_Horizontal

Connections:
AUDIO_L: J6.6, J9.6
AUDIO_R: J6.7, J9.7
B: J6.3, J9.3, R3.2
DIGITAL_B: J1.8, J4.6, J5.5, R3.1
DIGITAL_G: J1.7, J4.4, J5.4, R2.1
DIGITAL_R: J1.6, J4.2, J5.3, R1.1
G: J6.2, J9.2, R2.2
GND: H1.1, H2.1, H3.1, H4.1, J1.2, J4.1, J5.0, J5.2, J6.8, J9.8
HSYNC: J1.4, J4.3, J5.8, J6.4, J9.4
R: J6.1, J9.1, R1.2
VSYNC: J1.5, J4.5, J5.9, J6.5, J9.5

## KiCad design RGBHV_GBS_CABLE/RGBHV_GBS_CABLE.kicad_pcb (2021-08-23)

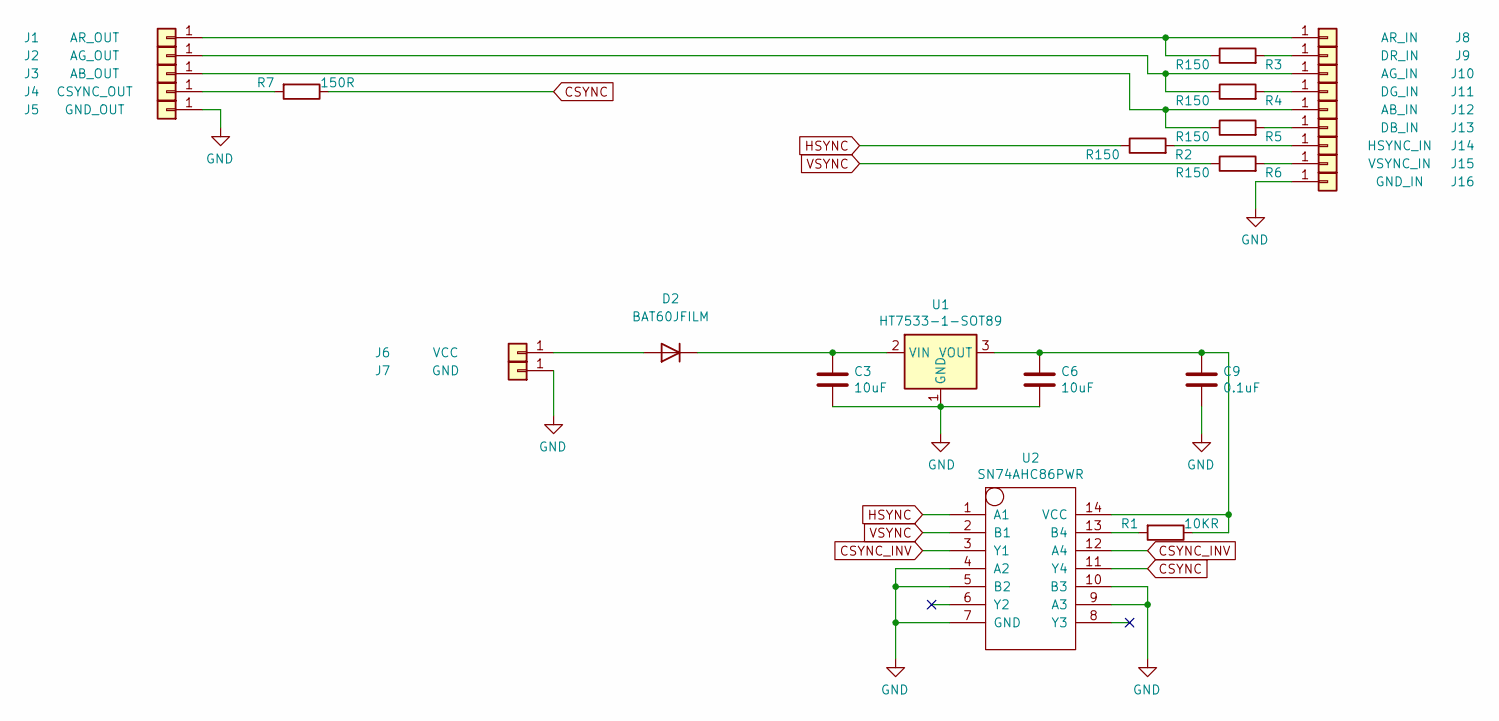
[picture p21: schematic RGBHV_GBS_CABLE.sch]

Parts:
C3, C6: 10uF; C_0805_2012Metric
C9: 0.1uF; C_0402_1005Metric
D2: BAT60JFILM; D_SOD-323
J1: AR_OUT; PAD
J2: AG_OUT; PAD
J3: AB_OUT; PAD
J4: CSYNC_OUT; PAD
J5: GND_OUT; PAD
J6: VCC; PAD
J7: GND; PAD
J8: AR_IN; PAD
J9: DR_IN; PAD
J10: AG_IN; PAD
J11: DG_IN; PAD
J12: AB_IN; PAD
J13: DB_IN; PAD
J14: HSYNC_IN; PAD
J15: VSYNC_IN; PAD
J16: GND_IN; PAD
R1: 10KR; R_0402_1005Metric
R2, R3, R4, R5, R6: R150; R_0402_1005Metric
R7: 150R; R_0402_1005Metric
U1: HT7533-1-SOT89; SOT-89-3
U2: SN74AHC86PWR; TSSOP-14_4.4x5mm_P0.65mm

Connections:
CSYNC: R7.1, U2.11 (Y4)
CSYNC_INV: U2.3 (Y1), U2.12 (A4)
GND: C3.2, C6.2, C9.2, J5.1, J7.1, J16.1, U1.1 (GND), U2.4 (A2), U2.5 (B2), U2.7 (GND), U2.9 (A3), U2.10 (B3)
HSYNC: R2.1, U2.1 (A1)
unnamed: C3.1, D2.1 (K), U1.2 (VIN)
unnamed: C6.1, C9.1, R1.1, U1.3 (VOUT), U2.14 (VCC)
unnamed: D2.2 (A), J6.1
unnamed: J1.1, J8.1, R3.1
unnamed: J4.1, R7.2
unnamed: J9.1, R3.2
unnamed: J2.1, J10.1, R4.1
unnamed: J11.1, R4.2
unnamed: J3.1, J12.1, R5.1
unnamed: J13.1, R5.2
unnamed: J14.1, R2.2
unnamed: J15.1, R6.2
unnamed: R1.2, U2.13 (B4)
VSYNC: R6.1, U2.2 (B1)

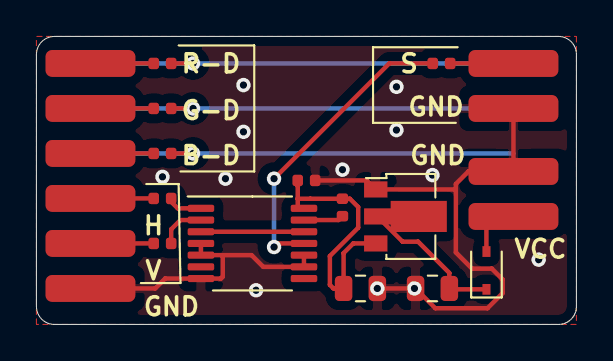
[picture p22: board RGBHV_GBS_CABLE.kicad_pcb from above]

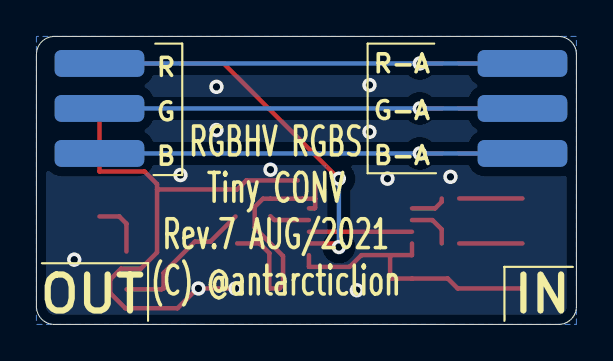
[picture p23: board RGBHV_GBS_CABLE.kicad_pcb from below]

Board: 2 copper layers, 30.0 x 16.0 mm, 29 parts (6 on the bottom side), 18 nets.

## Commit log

2019-03-03 Initial upload
    [RGBHV_RGBS_CONV.kicad_pcb, RGBHV_RGBS_CONV.sch]
2019-03-03 訂正
    ✕ とりあえずJ14とJ10にジャンパを付けてください。
    〇 とりあえずJ14とJ13にジャンパを付けてください。
2019-03-04 訂正
    ✕ Rev0.4b
    〇 Rev0.4a
2019-08-28 Rev.5A DIn8 fix and remove sync sep.
    [RGBHV_RGBS_CONV.kicad_pcb, RGBHV_RGBS_CONV.sch]
2020-03-25 Rev 0.5B pre-release
    説明を書いている時間が無いので取り急ぎ検証済みのガーバーデータだけ。
2020-06-09 Rev.5B Add RGBS VR
    [RGBHV_RGBS_CONV.kicad_pcb, RGBHV_RGBS_CONV.sch]
2021-05-11 initial upload
    Rev 1.0B gerber
2021-07-09 Rev1.0C
    レギュレータのパターンを追加。
    RGBS XHコネクタへの音声パターンカット
    [RGBHV_RGBS_CONV.kicad_pcb, RGBHV_RGBS_CONV.sch]
2021-07-29 Rev 1.0D
    Fix DIN8 R-G H-V pin swap bug
    [RGBHV_RGBS_CONV.kicad_pcb, RGBHV_RGBS_CONV.sch]
2021-07-29 Rev1.0D
    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
2021-08-23 add RGBHV_GBS_CABLE
    ケーブル中継ケースに内蔵する子基板を追加
    [RGBHV_GBS_CABLE.kicad_pcb, RGBHV_GBS_CABLE.sch]
2021-09-11 Initial upload
    Stack plate to mount conv pcb on GBS
    [RGBHV_RGBS_CONV_stack.kicad_pcb]
2022-09-22 Delete RGBHV_RGBS_CONV05A.zip
    旧ファイルの削除
2022-09-22 Delete RGBHV_RGBS_CONV05B.zip
    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
2022-09-22 Delete RGBHV_RGBS_CONV_04.zip
    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
2022-09-22 Delete RGBHV_RGBS_CONV_04A.zip
    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
2022-09-22 Delete RGBHV_RGBS_CONV_10B2.zip
    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
2022-09-22 Delete RGBHV_RGBS_CONV_10C.zip
    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
2022-09-22 格納位置変更のため再アップロード
2022-09-22 Rev1.5 リリース候補
2022-09-22 Rev1.5リリース候補
    [RGBHV_RGBS_CONV_EXTRA1.kicad_pcb, RGBHV_RGBS_CONV_EXTRA1.sch]
2022-10-03 Fix switch hole size
2022-10-04 錯誤の修正

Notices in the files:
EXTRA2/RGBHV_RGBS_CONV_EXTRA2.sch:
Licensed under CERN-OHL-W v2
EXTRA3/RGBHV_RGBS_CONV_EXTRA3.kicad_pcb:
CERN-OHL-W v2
